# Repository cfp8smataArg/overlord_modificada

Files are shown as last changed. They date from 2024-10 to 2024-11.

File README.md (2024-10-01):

# Adaptación de impresora 3D Overlord Pro+
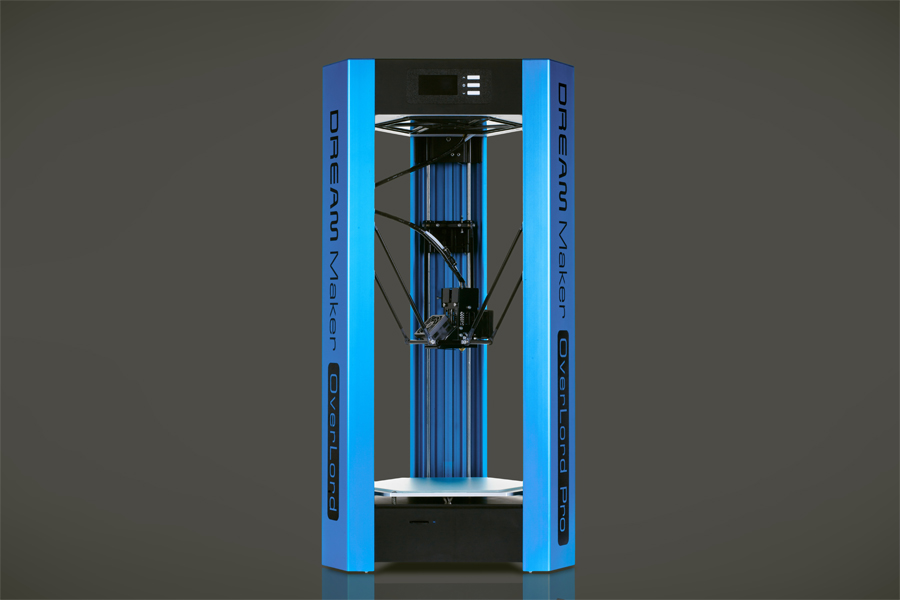
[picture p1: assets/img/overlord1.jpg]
overlord


El proyecto consiste en convertir la impresora 3D Overlord Pro+, de la empresa china Dream Maker, en una versión adaptable, de bajo costo, realizada con insumos mundialmente ultilizados por la comunidad maker y de facil acceso a nivel nacional.

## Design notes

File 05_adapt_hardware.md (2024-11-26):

---
title: Adaptación del hardware
layout: default
filename: 05_adapt_hardware.md
--- 
# Adaptación del hardware

En la sección [Planificación](./03_planificacion.html), se retiraron las partes de la estructura que cubren y protegen el cableado y la electrónica de la impresora 3D. Esto se hizo con el objetivo de despejar las zonas por las que se modificará el cableado original, se cambiarán los sensores y la electrónica de control.

Si la etapa de _Planificación_ fue realizada, la adaptación del hardware debe hacerse de forma ordenada, buscando que no exista ninguna confusión en el conexionado.
Antes de empezar con la adaptación del hardware, es importante saber que, debido a la [geometría delta](https://reprap.org/wiki/Delta_geometry) de la impresora 3D, el equipo tiene una gran extensión de partes cableadas. Para entender la estructura general de este cableado es importante tener los siguientes puntos bien presentes:

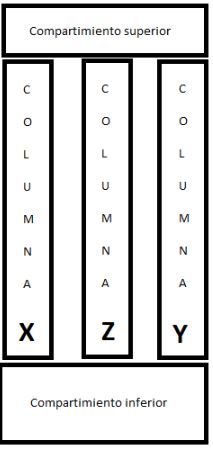
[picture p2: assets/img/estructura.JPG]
estructura


* La alimentación eléctrica que proviene de la fuente de alimentación de 24v ingresa desde un lateral del compartimiento inferior de la impresora 3D, de la misma manera que en el esquema original.
* Los motores de los tres ejes se encuentran en el compartimiento inferior.
* El final de carrera asociado a cada eje se ubica debajo de cada motor, sobre cada columna.

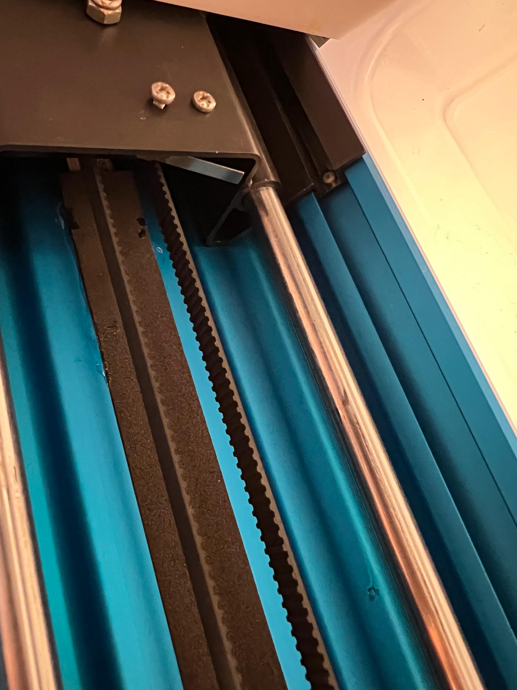
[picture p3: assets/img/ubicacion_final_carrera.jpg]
final_carrera
    

* El motor del extrusor se ubica dentro del compartimiento superior.

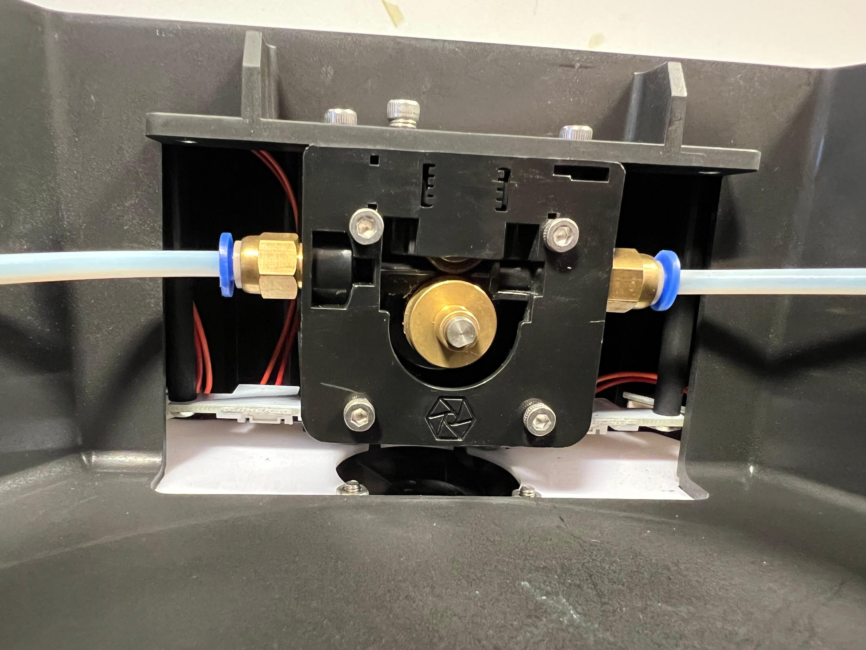
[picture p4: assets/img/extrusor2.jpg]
extrusor2
    

* En un costado de la parte interna del compartimiento superior, se ubica una placa pequeña, la cual interconecta todo el cableado eléctrico de algunos de los elementos que trabajan en bloque extrusor

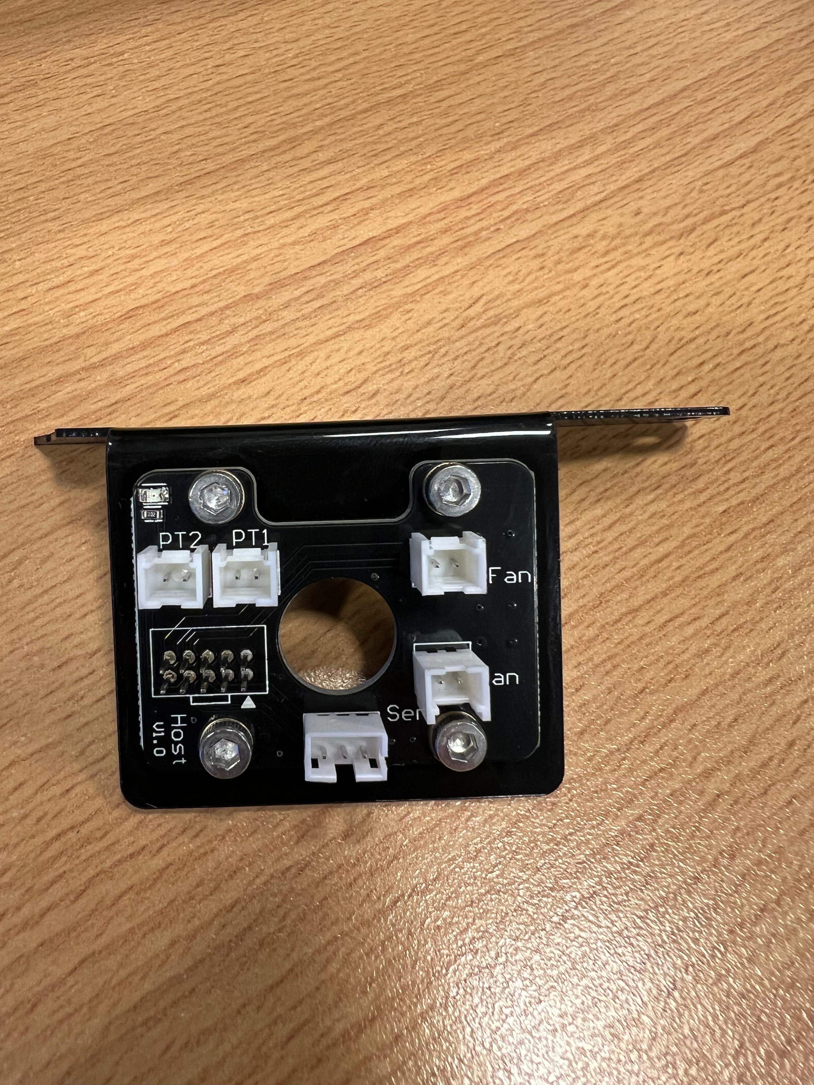
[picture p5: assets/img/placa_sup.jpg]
placa_sup
    

    Mediante un multímetro, es muy importante poder revisar el conexionado de todos los elementos que pasan por esta placa. Esto último ayudará a realizar el conexionado de los periféricos a la placa MKS.

* En el compartimiento inferior se ubica la placa de control MKS que controla la impresora 3D. Por las columnas desciende el cableado de todos los elementos que trabajan en el extrusor (coolers, calefactor 24v, termistor 100k).

## ¿Qué cables y elementos llegan al bloque extrusor?

Todos los elementos que llegan al extrusor lo hacen agrupados mediante un _spaghetti_. Estos elementos son los siguientes:

* Tubo de nylon por donde llega el filamento
* Cable del calefactor de 24V
* Cable del termistor NTC del bloque calentador
* Cable de 24v para los dos ventiladores de capa
* Cable de 24v para el ventilador del disipador

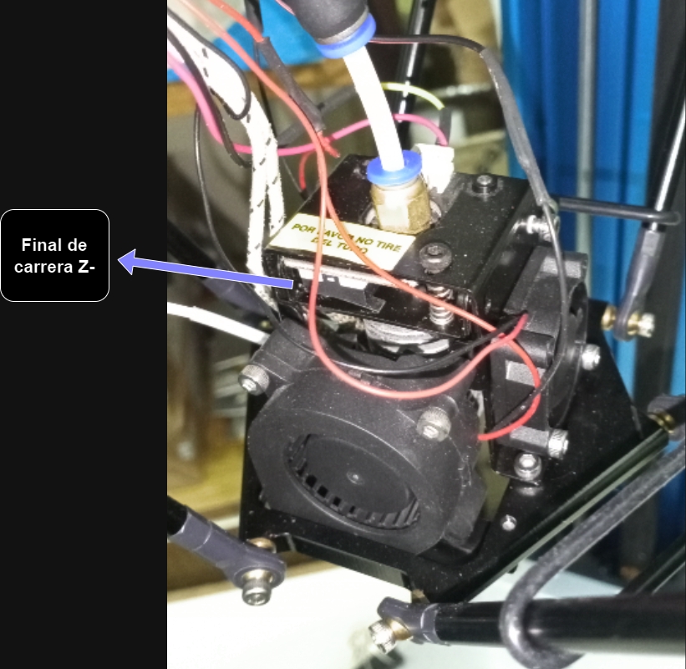
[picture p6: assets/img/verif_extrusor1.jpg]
verif_extrusor1

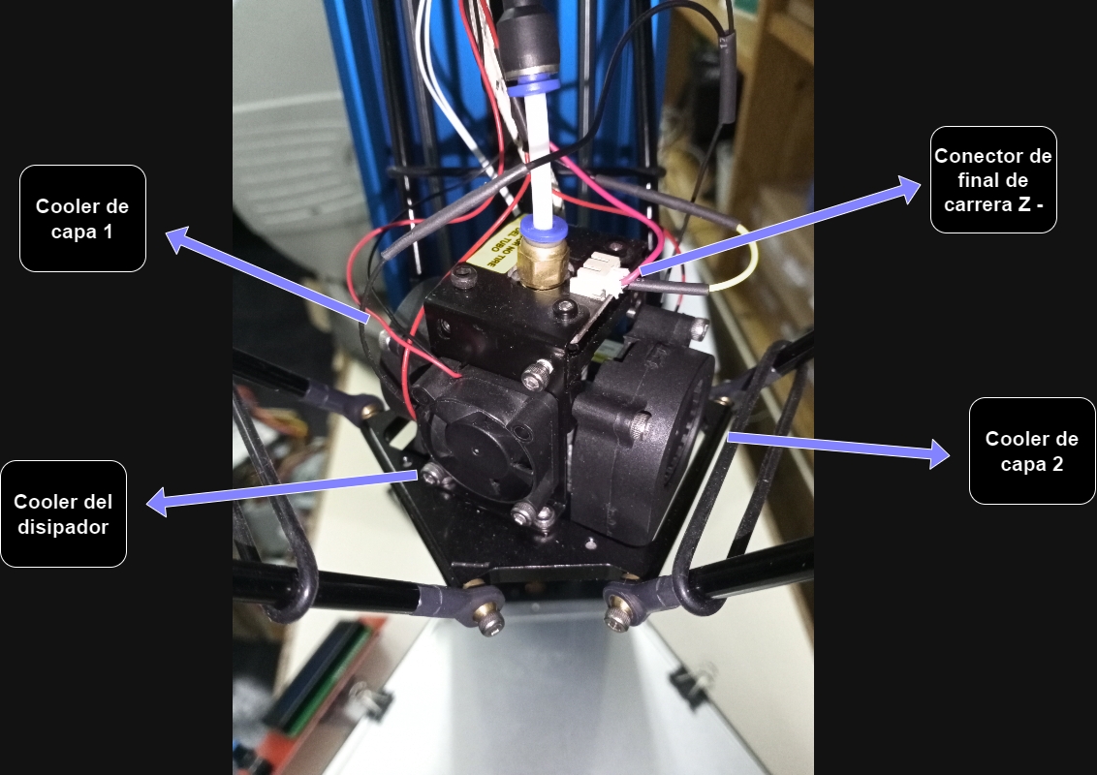
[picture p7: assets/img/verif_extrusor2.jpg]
verif_extrusor2

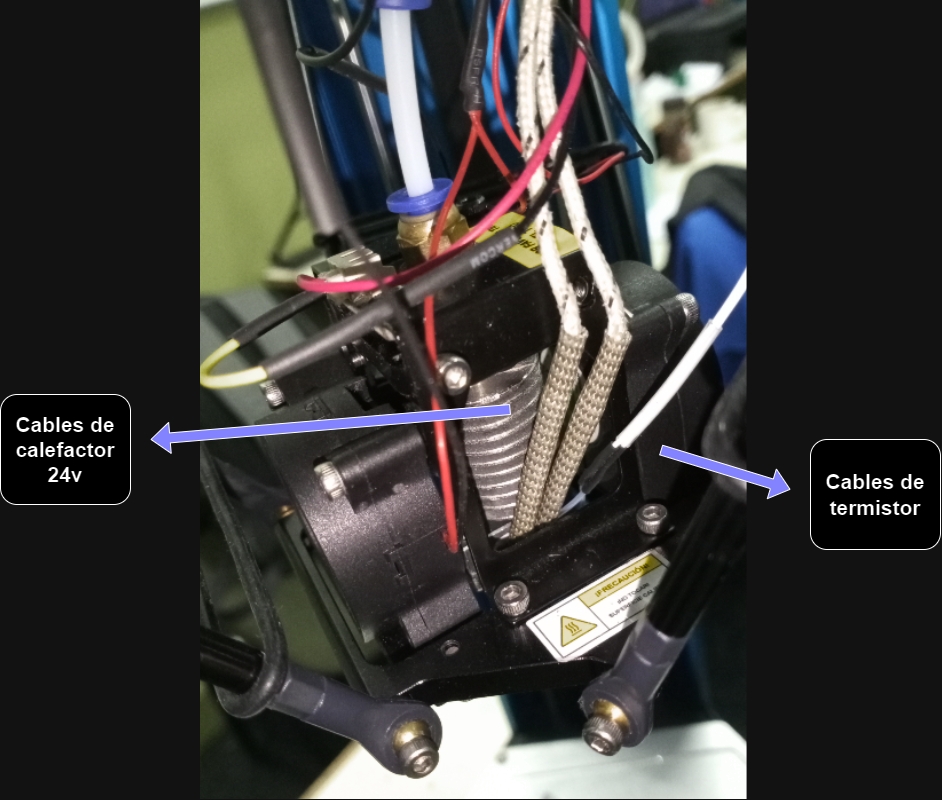
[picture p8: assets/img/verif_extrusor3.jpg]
verif_extrusor3

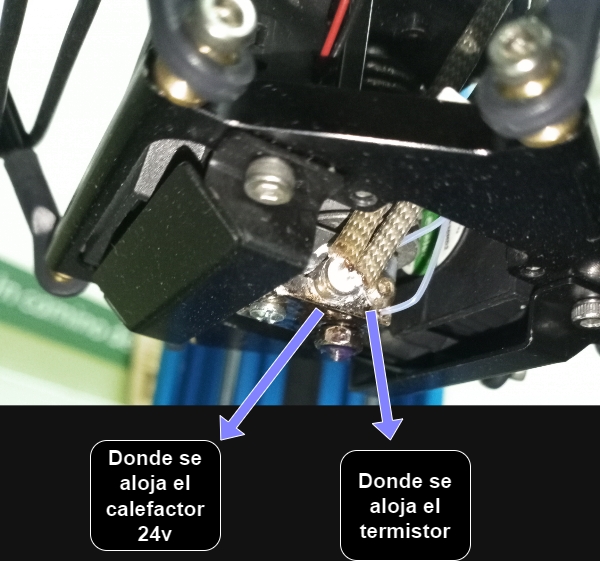
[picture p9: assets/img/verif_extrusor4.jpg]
verif_extrusor4


## Calibración de los drivers

El proceso de calibración de los drivers utilizados por los motores NEMA se muestra detalladamente en este [video](https://www.youtube.com/watch?v=GzAly4MJ4PU) para el driver **A4988** y este [video](https://www.youtube.com/watch?v=m1fOqq5GYDA) para el driver **DRV8825** _(Audio en inglés, pero tiene subtitulos en español)_.

## Adaptación de la fuente de alimentación

La fuente de alimentación original presenta en su cable un conector hembra de cuatro pines (dos para +24v y dos para GND). El conector macho es propio de la placa de control original del equipo. Dado que no es un conector fácil de encontrar en el mercado local, en este caso se reemplazó por una simple bornera de dos pines. Esto puede reemplazarse por otro conector que sea del gusto del usuario.

A continuación, están las imágenes del conector original del cargador y el conector original en el chasis de la impresora.

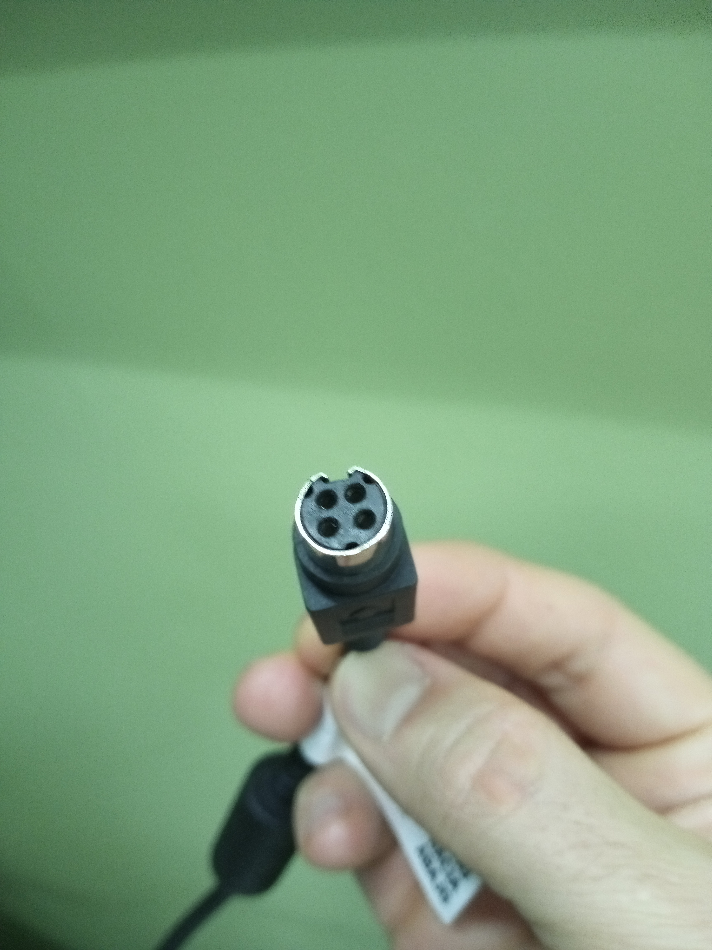
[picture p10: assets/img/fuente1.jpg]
fuente1

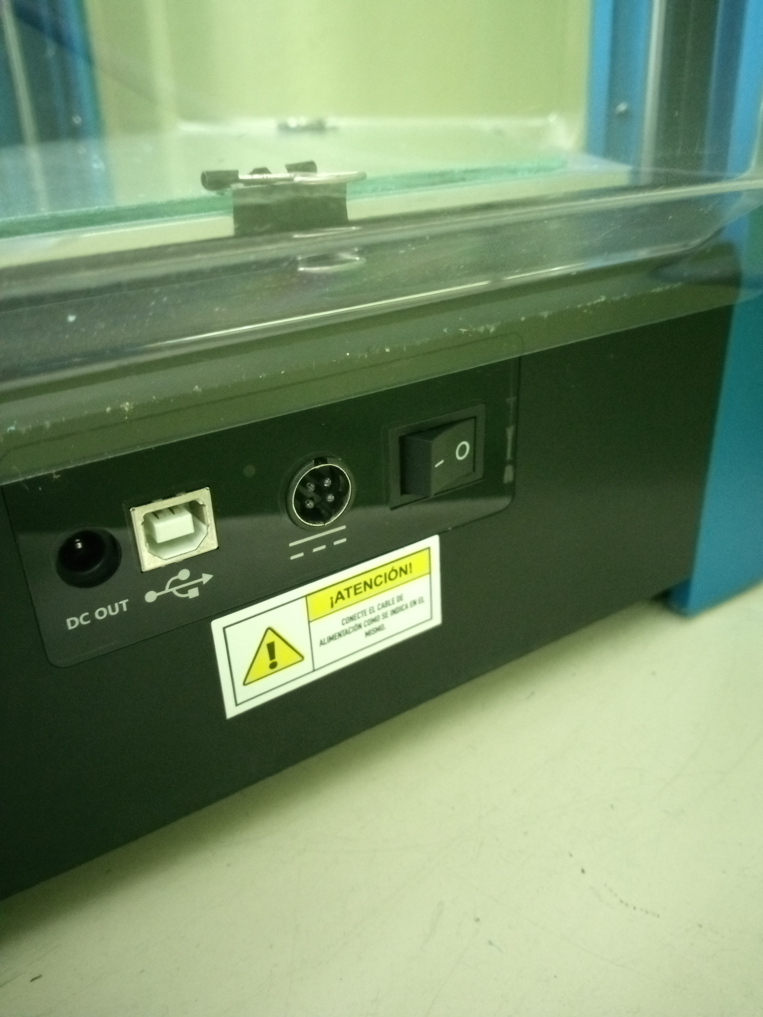
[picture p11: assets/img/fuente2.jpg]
fuente2


A continuación, están las imágenes donde se retira el conector y se dejan los dos cables libres y la bornera de dos pines para atornillar. El cable celeste y marrón son los de +24v y GND que ingresan a la impresora y alimentan todos los circuitos.

fuente3
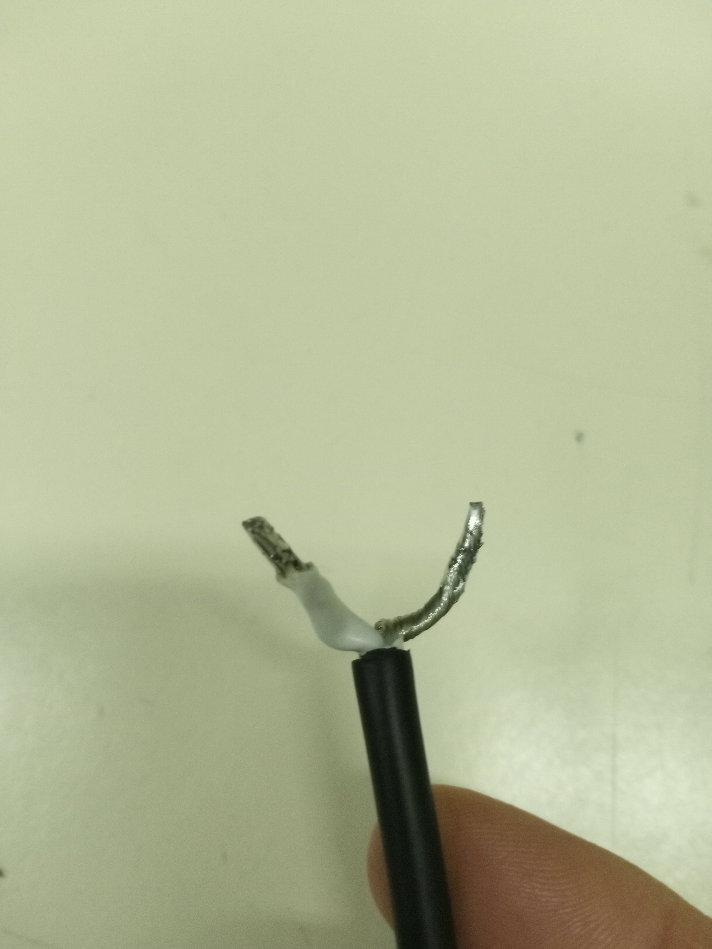
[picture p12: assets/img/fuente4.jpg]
fuente4


Firmware Puesta en marcha

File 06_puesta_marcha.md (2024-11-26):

---
title: Puesta en marcha
layout: default
filename: 06_puesta_marcha.md
--- 
# Puesta en marcha

Antes de comenzar a usar la impresora 3D por primera vez, es importante realizar una verificación de distintos módulos con el objetivo de prevenir algún posible accidente. Dado esto, es importante:

* Con un multímetro, verificar que la fuente de alimentación entrega el voltaje correcto.
* Verificar el cableado interno del equipo, asegurando que los cables no se enreden en el área de movimiento de los motores.
* Verificar la integridad de las correas en los tres ejes.
* Inspeccionar el extrusor y controlar todas las conexiones eléctricas que existen en él.
* Verificar las conexiones de todos los elementos en las placa de control.

Si los chequeos anteriores fueron realizados, avanzar con el encendido del equipo. El display se encenderá y aparecerá un menú como el de las siguientes imágenes.

marlin1
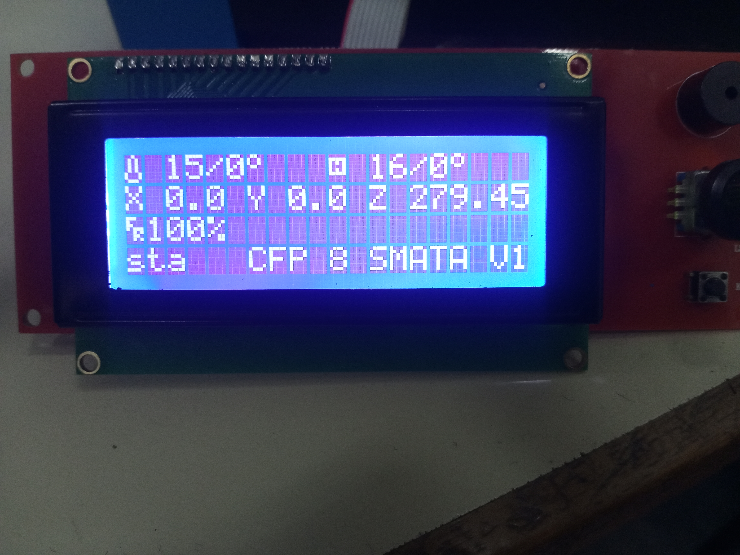
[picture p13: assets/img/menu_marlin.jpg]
marlin2


Hardware calibracion

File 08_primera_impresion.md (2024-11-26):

---
title: Mi primera impresión
layout: default
filename: 08_primera_impresion.md
--- 
# Mi primera impresión

La impresora 3D se opera de la misma manera que cualquier impresora 3D comercial.

1. Verificar que la cama caliente no presente suciedad. En caso de que sí exista, limpiarla con alcohol y un paño. 
2. Verificar que haya filamento cargado en la impresora 3D.
3. Cargar el archivo _.gcode_ a imprimir dentro de una memoria SD.
4. La memoria SD se inserta en el slot ubicado en el lateral del display LCD.
5. Al insertar la memoria SD, aparecerá la leyenda _SD/FD insertado_
6. Para lanzar la impresión, presionar el encoder, ir a la opción _Imprimir desde SD/FD_ y seleccionar el archivo a imprimir.

ATENCIÓN: En caso de atasco, nunca remover el tramo inferior del tubo de teflón (se muestra en la siguiente imagen) ya que una mala posición puede generar un desborde del filamento fundido y un posterior tapón y atasco de plástico.

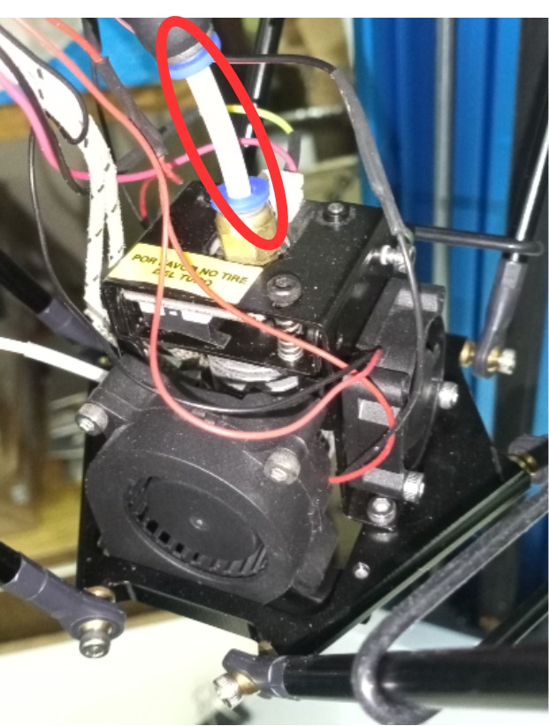
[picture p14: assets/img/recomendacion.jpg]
atención


# Demo

En el siguiente [link](https://drive.google.com/file/d/11Ifzz-wFGjBvnHKF1wgRUvqJJxLNcwyR/view?usp=sharing) se accede a un video demostración de la impresora 3D en funcionamiento. La impresión que se muestra en el video se realiza a 90 mm/s. A continuación, se muestra algunas imágenes de la impresión terminada.
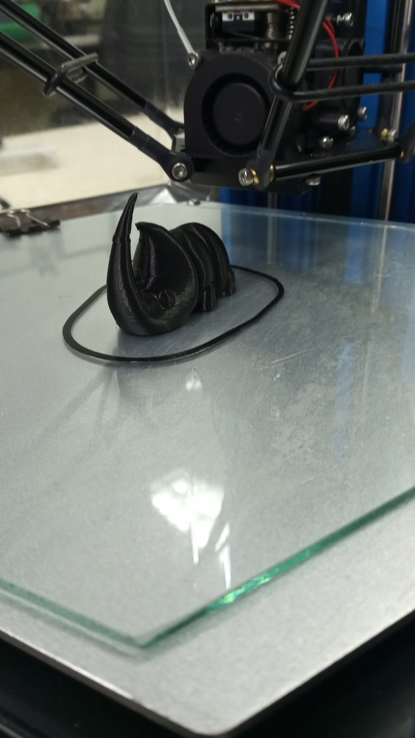
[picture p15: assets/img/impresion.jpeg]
impresion

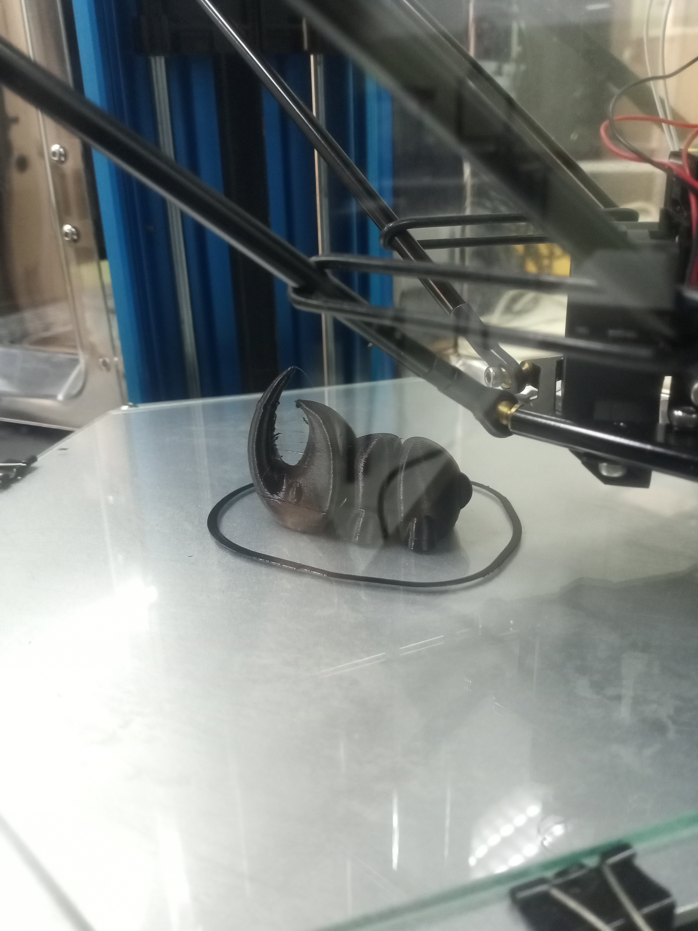
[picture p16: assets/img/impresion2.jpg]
impresion2


calibracion Agradecimientos

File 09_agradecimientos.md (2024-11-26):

---
title: Agradecimientos
layout: default
filename: 09_agradecimientos.md
--- 
# Agradecimientos
Este proyecto fue logrado gracias al apoyo y al trabajo del Centro de Formación Profesional Nº8 - SMATA y del INET. Este tipo de proyectos busca poner en valor recursos de las instituciones educativas de una forma simple y accesible, para que estudiantes y docentes de distintas puntos del país puedan poner en práctica los conocimientos vinculados a distintas áreas que son parte de la educación técnica como la robótica, el diseño y la impresión 3D, la electrónica, la programación y demás.

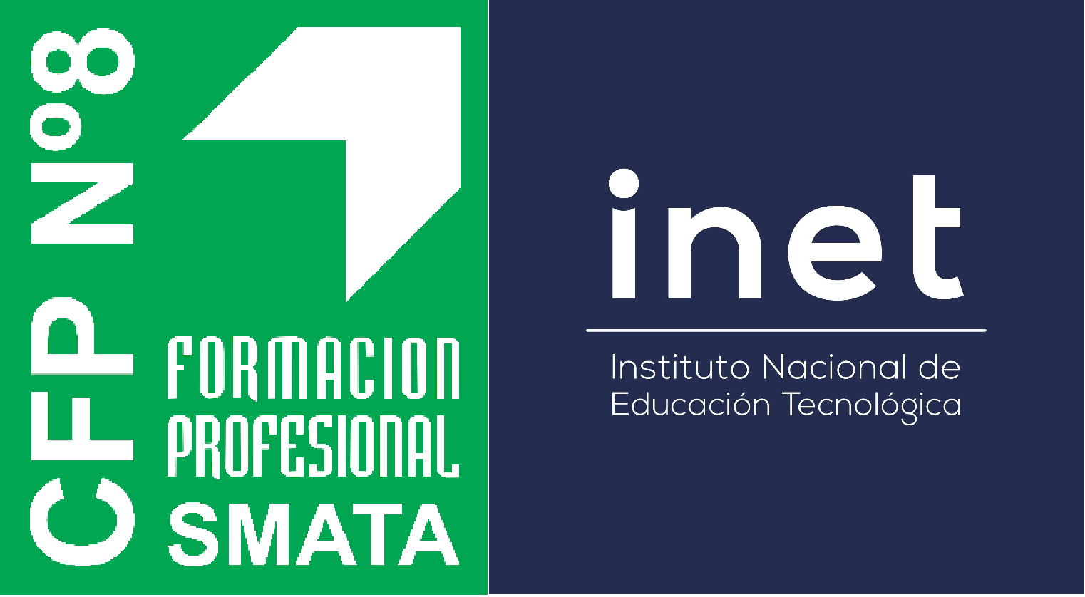
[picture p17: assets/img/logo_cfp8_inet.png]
logo_cfp8


Invitamos a todos los interesados a que puedan llevar adelante este tipo de proyectos y que puedan fomentar su creatividad y trabajo en equipo con el objetivo de apoyar el desarrollo de recursos educativos. Que la tecnología sea un medio de intercambio de ideas y motivaciones para todos los estudiantes.

Primera impresión

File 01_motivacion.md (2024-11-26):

---
title: Motivaciones y objetivos
layout: default
filename: 01_motivacion.md
--- 
# Motivaciones y objetivos
Desde el año 2019, el [Instituto Nacional de Educación Tecnológica (INET)](https://www.inet.edu.ar/) entregó a distintas instituciones educativas técnicas de todo el país cerca de 6000 impresoras 3D [Overlord Pro+](https://www.dfrobot.com/product-1298.html) con la intención de fomentar el diseño y la impresión 3D.

En el año 2020, la llegada de la pandemia intensificó el uso de este tipo de equipos para la impresión de vinchas para máscaras de protección contra el virus del COVID-19. La presencia de las impresoras 3D Overlord Pro+ en las escuelas generó que muchos establecimientos fueran centros de producción de vinchas a lo largo y a lo ancho del país.

Como cualquier dispositivo de uso cotidiano, las impresoras 3D requieren un mantenimiento preventivo y correctivo al sumar horas de uso. Las impresoras 3D Overlord Pro+ tienen la ventaja de que pueden ser puestas en funcionamiento de forma rápida y en pocos pasos, pero sus desventajas llegan cuando aparecen desperfectos técnicos.

Al pasar el tiempo, muchas de las impresoras 3D Overlord Pro+ que estaban en funcionamiento comenzaron a presentar desperfectos técnicos y comenzaron a dejar de utilizarse.

Una de las principales desventajas de este modelo de impresora 3D es que presenta un diseño “propietario”. ¿Qué significa eso? todas sus partes (firmware, electrónica, etc) son únicos de este modelo y no utilizan opciones genéricas o repuestos alternativos, como si lo hacen otros modelos de impresoras 3D de otras marcas del mercado local e internacional. Esto genera una gran dificultad para encontrar los repuestos necesarios, los cuales generalmente se encuentran discontinuados o presentan costos muy elevados.

El proyecto [RepRap](https://reprap.org/wiki/RepRap) propone el desarrollo de impresoras 3D a partir de diseños _Open Source_, entonces nos interesaba utilizar todo el conocimiento volcado sobre este proyecto colaborativo de escala mundial a la masa de impresoras 3D que podrían estar en desuso en las escuelas de toda la República Argentina.

>Una impresora 3D es una herramienta de trabajo y estudio invaluable, la cual dentro de una institución educativa o laboratorio tecnológico, permite estimular creatividad de forma ilimitada.

_"¿Cómo podemos hacer para que la impresora 3D Overlord Pro+ pueda ser lo más “genérica” posible?"_ _¿Como podemos hacer para que estas impresoras 3D puedan funcionar con insumos que puedan adquirirse en el mercado local a un bajo costo?_ _¿Cómo podemos hacer para que estas impresoras 3D se manejen como la mayoría de las impresoras 3D de uso doméstico a nivel mundial?_ Esto se preguntaron el Esp. Ing. Nicolás Vargas Alice y Freddy Fores, especialistas en diseño e impresión 3D, robótica y electrónica, quienes ademas son docentes del [Centro de Formación Profesional Nº8 - SMATA](https://centro8smata.org.ar/) e INET.

|:-----------------------------------------:|:------------------------------------------:|
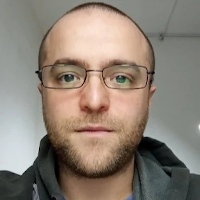
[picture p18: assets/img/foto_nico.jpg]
foto Nicolás
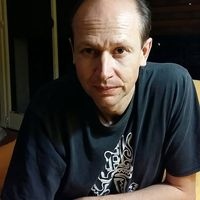
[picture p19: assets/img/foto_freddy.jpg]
foto Freddy
|||
|:-----------------------------------------:|:------------------------------------------:|
|      Esp. Ing. Nicolás Vargas Alice       |                     Freddy Forés           |

Desde inicios del año 2022 Nicolás y Freddy comenzaron a pensar las respuestas a todas estas preguntas. El equipo de trabajo comenzó a estudiar el funcionamiento de la impresora 3D, sus partes, la información disponible por parte del fabricante, etc. Luego de una etapa de estudio a investigación, se llegaron a las siguientes conclusiones:

* La impresora 3D presenta una excelente estructura mecánica.
* Las partes de la impresora 3D eran extremadamente costosas y muy complejas de conseguir en el mercado argentino.
* La documentación técnica existente era casi nula.
* El soporte técnico por parte del fabricante era inexistente.

A partir de estos cuatro puntos, se propuso desarrollar una adaptación de la impresora 3D que se base en: 
* Reutilizar partes originales de la impresora 3D
* Combinar las partes recicladas con insumos mas economicos y accesibles en el mercado local.
* Que el sistema de control de la impresora se base en un sistema fácil de configurar, simple de utilizar y con una amplia comunidad de usuarios a nivel mundial.
* Que el proceso completo de adaptación sea lo más accesible y claro para que estudiantes y docentes de las escuelas puedan ponerlo en práctica.

Inicio Materiales necesarios

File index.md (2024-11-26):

---
layout: default
---
# Bienvenidos al Proyecto!
En este sitio se encuentra el procedimiento detallado para realizar una posible adaptación de una impresora 3D modelo **Overlord Pro+** de la empresa **Dream Maker**. Esperamos que el trabajo relizado sea de utilidad y pueda ser puesto en práctica por parte de cualquier persona interesada.

El sitio está dividido en secciones que incluyen imágenes, enlaces de consulta e información complementaria que guían al usuario en la implementacion del proyecto.

# Antes de comenzar...
El proyecto fue desarrollado con la intención de que cualquier persona con mínimos conocimientos de electrónica y/o impresión 3D pueda implementarlo. Así todo, se recomienda leer detenidamente la información volcada en este sitio web y ante cualquier duda, comunicarse con los desarrolladores.

# Etapas del proyecto
Motivación  Materiales necesarios  Planificación

Firmware  Hardware  Puesta en marcha

calibracion  Primera impresión  Agradecimientos

# Contacto
Ante cualquier duda o consulta, comunicarse vía mail a: **inet.impresoras3d@gmail.com**

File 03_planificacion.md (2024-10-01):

---
title: Planificación
layout: default
filename: 03_planificacion.md
--- 
# Planificación

La etapa de planificación, como muchas de este proyecto, son modificables a gusto de las personas que lo estén llevando a cabo. El orden de estas tareas son únicamente una sugerencia propuesta. La idea de este paso es retirar partes del gabinete que protegen  parte del cableado y otros módulos para poder realizar cómodamente el retiro de las partes que no se utilizarán, las modificaciones en las partes a reutilizar e instalar las partes nuevas. 

Antes de comenzar, es bueno tener presente una vista integral de la impresora. La misma se puede observar en las siguientes imágenes, donde además se indican las partes principales de la misma.

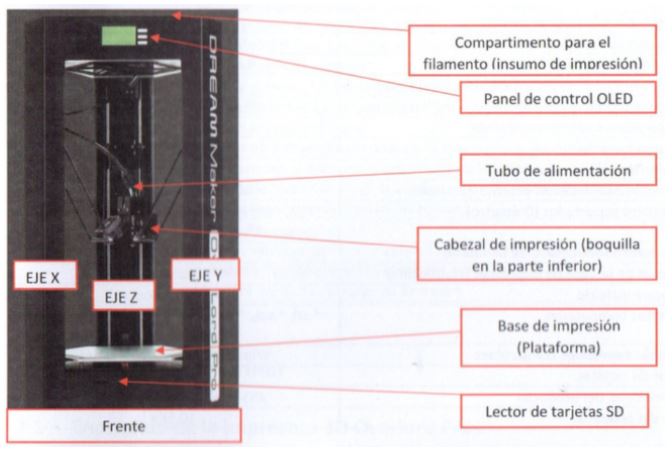
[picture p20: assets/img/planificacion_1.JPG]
planificacion_01

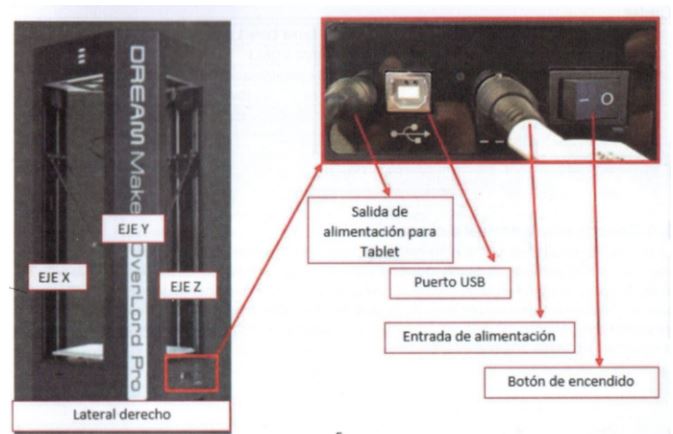
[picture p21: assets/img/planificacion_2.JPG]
planificacion_02


Teniendo presente esto, los pasos a seguir serían los siguientes:
* En el compartimiento superior, retirar la bobina de filamento que pueda estar utilizándose en la impresora 3D.
* Con un destornillador philips, retirar los paneles plásticos transparentes de los laterales y la tapa inferior que cubre la electrónica y parte del cableado de la impresora 3D.

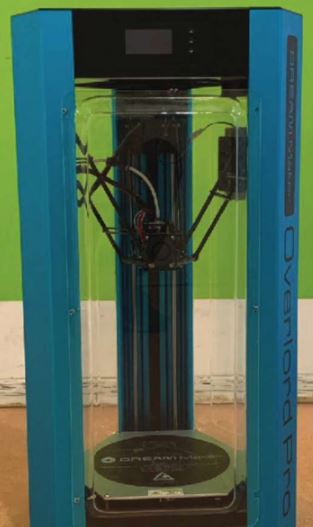
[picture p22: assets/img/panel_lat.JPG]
planificacion_03

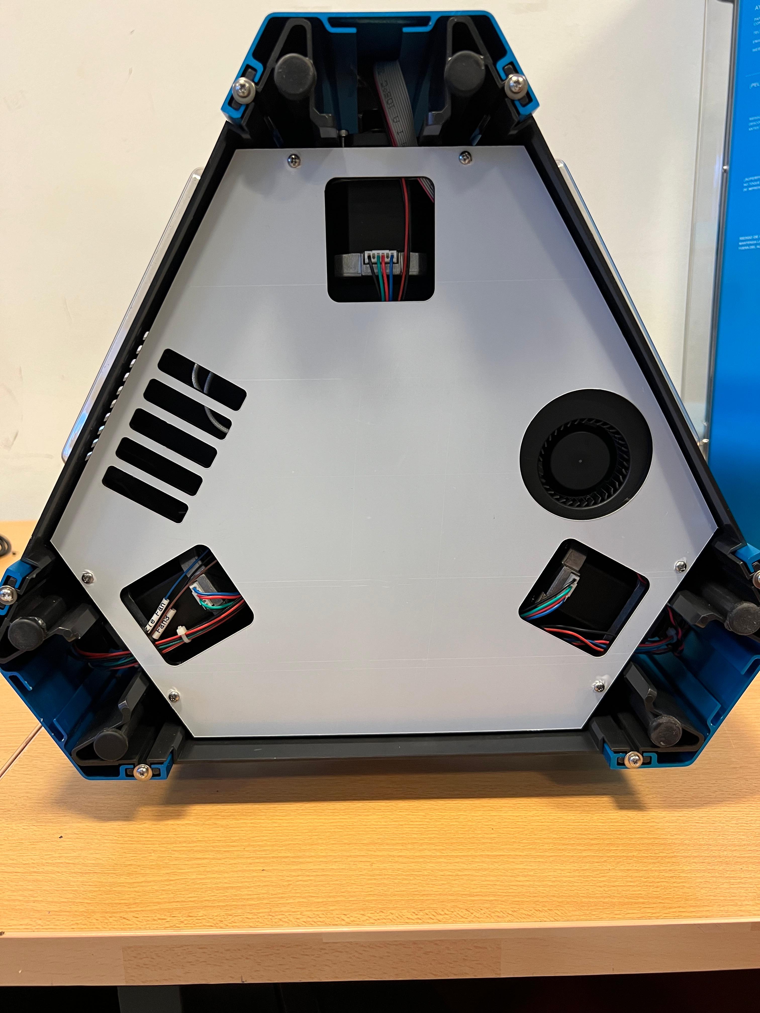
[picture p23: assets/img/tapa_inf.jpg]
planificacion_04


* El la parte inferior, debe observarse algo como lo de la siguiente imagen.

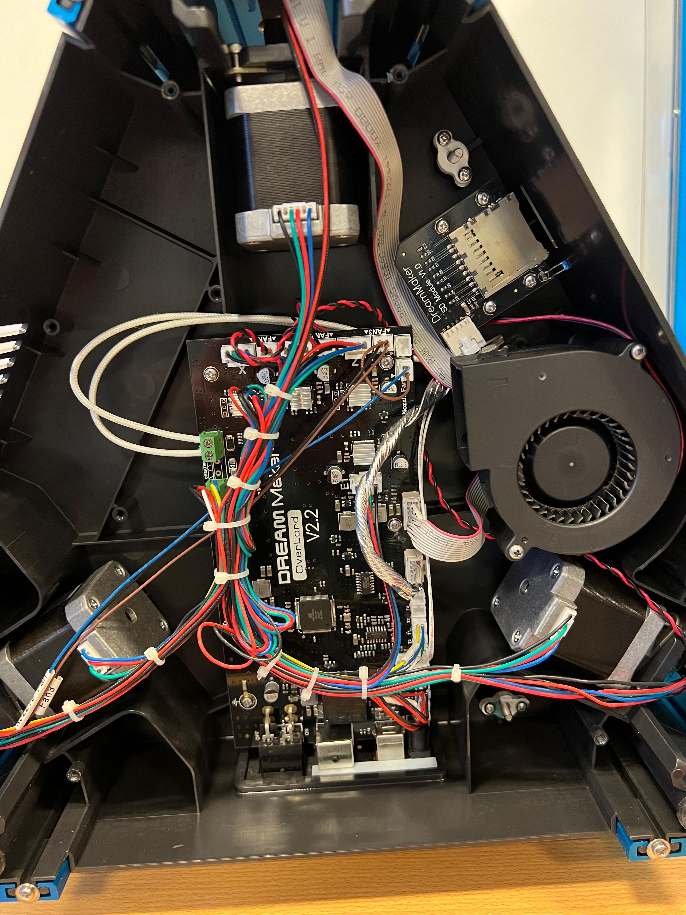
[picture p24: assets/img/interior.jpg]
planificacion_05


* Remover el covertor “__spaghetti__” que reúne el tubo de teflón blanco con cables que terminan en la zona del extrusor.
* Remover los perfiles celestes de las columnas. Para hacer esto, con un destornillador philips, remover los tornillos desde la parte inferior de la impresora 3D y deslizar los perfiles como muestran las siguientes imágenes.

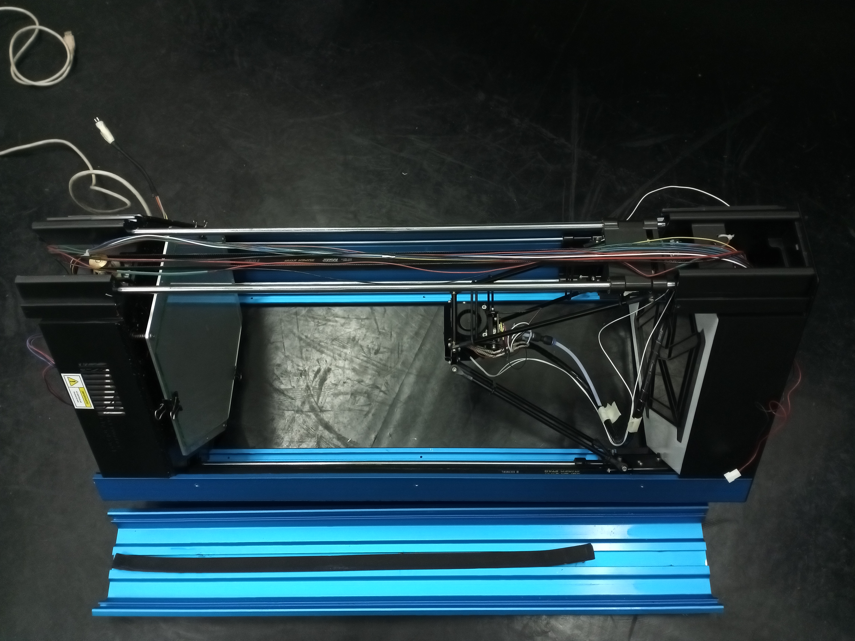
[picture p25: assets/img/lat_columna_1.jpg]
planificacion_06

planificacion_07

Materiales necesarios Firmware

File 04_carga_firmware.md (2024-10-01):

---
title: Instalación del firmware
layout: default
filename: 04_carga_firmware.md
--- 
# Antes de comenzar esta etapa

El firmware utilizado en este proyecto fue el Marlin 2.1.2. Se descargó el proyecto base desde la página oficial del __Proyecto Marlin__ y se modificó hasta lograr una versión funcional. La situación actual respecto al hardware (la placa MKS Gel-L v1.0 está discontinuada por el fabricante, pero aún se encuentran unidades a la venta. Se lanzó la placa [MKS TinyBee](https://github.com/makerbase-mks/MKS-TinyBee) como reemplazo) hace que **en este procedimiento mostremos la carga del firmware para ambas placas**.

Sin importar la placa con la que se trabaje, es importante tener una PC con los siguientes programas instalados:

* **Visual Studio Code**: IDE de programación mundialmente utilizado con el cual se puede modificar el código del firmware, compilarlo y cargarlo. De descarga desde este [link](https://drive.google.com/drive/folders/1mMvHacDkfZcnlTN5KPSEYk4WfQkbPL_f?usp=drive_link)
* **XLoader**: Programa para cargar archivos **.HEX** en la placa. Se descarga desde este [link](https://drive.google.com/drive/folders/1mMvHacDkfZcnlTN5KPSEYk4WfQkbPL_f?usp=drive_link).
* **Pronterface (Opcional)**: Programa para enviar comandos G a la impresora 3D y probar si la impresora interpreta bien los comandos. Se descarga desde este [link](https://www.pronterface.com/).

# Instalación del firmware en MKS Gen-L v1.0

Para instalar el firmware, proponemos dos opciones: 
* La primera opción es cargando el archivo **firmware.hex** mediante el programa **XLoader**, recomendada para usuarios que no tienen mucha experiencia en programación y prefieren hacerlo en pocos pasos. 
* La segunda opción es para usuarios que ya presentan alguna experiencia en programación, quieren explorar las opciones habilitadas dentro del código del Marlin o ya utilizaron los programas que se describieron más arriba. 

### Mediante programa XLoader

xloader

1. Conectar la placa a una PC mediante un cable USB Tipo B.
2. Con la placa conectada a la PC, abro el programa **XLoader**.
3. En _Device_, selecciono **Mega (ATMEGA2560)**.
4. En _COM port_, selecciono el puerto COM a donde tengo conectada la placa.
5. En _Hex File_, selecciono el archivo **.hex** (se descarga desde este [link](https://drive.google.com/drive/folders/1mMvHacDkfZcnlTN5KPSEYk4WfQkbPL_f?usp=drive_link))
6. Configurado todo, presiono el botón _Upload_.
7. Luego de unos segundos, en la parte inferior debe aparecer una leyenda como _“xxxxx bytes uploaded”_.
8. Listo, la placa ya tiene el firmware instalado.

>¿Qué es un archivo ```.hex```?
>
>Es un archivo con la información completa que queremos cargar en la placa, pero escrito en el _lenguaje_ que entiende la placa. Para explicarlo de una manera simple y sin demasiados detalles técnicos, cuando en programación hablamos de _“compilar código”_ el programa que ejecuta el proceso de compilación toma el archivo escrito en el lenguaje que hayamos trabajado nosotros (Por ejemplo, _lenguaje C_ o _C++_), verifica que no existan errores y finalmente genera el archivo resultado con extensión _.hex_.

>¿Qué es _código G_ O _G-Code_?
>
>El **G-Code** consta de comandos **G** y **M**, cada uno de ellos con un movimiento o acción asignado. La combinación de estos comandos permitirá a la impresora 3D entender qué patrón seguir con el fin de crear la pieza final. Entre los diferentes tipos de órdenes que interpreta la impresora 3D, encontramos comandos de movimiento, extrusión, calentamiento y detección en una secuencia.

### Mediante el programa Visual Studio Code

1. Con la placa conectada a la PC, abro el programa _Visual Studio Code_.
2. Instalar la extensión **Platformio** en el Visual Studio Code.
3. Abro el proyecto Marlin descargado desde este [link](https://drive.google.com/drive/folders/1mMvHacDkfZcnlTN5KPSEYk4WfQkbPL_f?usp=drive_link).
4. Una vez abierto el proyecto, me ubico en la barra inferior del programa y presiono la opción de **Upload** (tiene un icono de una flecha hacia la derecha).

    vsc1

5. Si no existió ningún problema, en la ventana **Console** debería aparecer un mensaje como el que muestra la siguiente imagen.

    vsc2

6. En caso de querer mas detalles del procedimiento, el el siguiente [link](https://marlinfw.org/docs/basics/install_platformio_vscode.html) se encuentra el procedimiento de carga explicado en el sitio del proyecto [Marlin](https://marlinfw.org/).

# Instalación del firmware en MKS TinyBee

Para cargar el firmware, también hay dos opciones: 
* Al igual que en el caso de la MKS Gen-L, la primera opción es cargando el archivo **firmware.bin** en una tarjeta microSD y energizar la placa mediante un cable USB C o la fuente de alimentación, opción recomendada para usuarios que no tienen mucha experiencia en programación y prefieren hacerlo en pocos pasos.
* La segunda opción es para usuarios que ya presentan alguna experiencia en programación, quieren explorar las opciones habilitadas dentro del código del Marlin o ya utilizaron los programas que se describieron más arriba.

### Mediante la carga del archivo **firmware.bin** en microSD

1. Descargar el archivo firmware.bin desde este [link](https://drive.google.com/drive/folders/1E1NkSHg_1MNqnraAo90TGFX9QdSg1mOr?usp=drive_link).
2. Cargar el archivo en una memoria micro SD manualmente.
3. Energizar la placa mediante un cable USB C a una PC o mediante la fuente de alimentación. Comenzará la instalación automáticamente.
4. Luego de que el firmware se haya instalado, extraer la memoria microSD. 
5. Para verificar que la instalación se hizo correctamente, abrir la memoria microSD en una PC. Si dentro de ella, hay un archivo **firmware.CUR**, esto indica que el firmware se instaló correctamente en la placa. Dicho archivo con extensión **.CUR** puede borrarse sin inconvenientes.

### Mediante el programa Visual Studio Code

1. Con la placa conectada a la PC, abro el programa _Visual Studio Code_.
2. Instalar la extensión **Platformio** en el Visual Studio Code.
3. Abro el proyecto Marlin descargado desde este [link](https://drive.google.com/drive/folders/1E1NkSHg_1MNqnraAo90TGFX9QdSg1mOr?usp=drive_link).
4. Una vez abierto el proyecto, me ubico en la barra inferior del programa y presiono la opción de **Upload** (tiene un icono de una flecha hacia la derecha).

    vsc1

5. Si no existió ningún problema, en la ventana **Console** debería aparecer un mensaje como el que muestra la siguiente imagen.

    vsc2

6. En caso de querer mas detalles del procedimiento, el el siguiente [link](https://marlinfw.org/docs/basics/install_platformio_vscode.html) se encuentra el procedimiento de carga explicado en el sitio del proyecto [Marlin](https://marlinfw.org/).

Planificación Hardware

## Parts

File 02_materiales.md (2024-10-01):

---
title: Materiales necesarios
layout: default
filename: 02_materiales.md
--- 
# Materiales necesarios

La lista de materiales se creó con el fin de optimizar y reutilizar la mayor cantidad de partes originales de la impresora 3D Overlord Pro+. En la siguiente lista se incorporan todos los elementos nuevos a adquirir, contemplando que los elementos originales existen y funcionan.

| **MKS GenL v1 (1 unidad)** |
|:---:|:---|
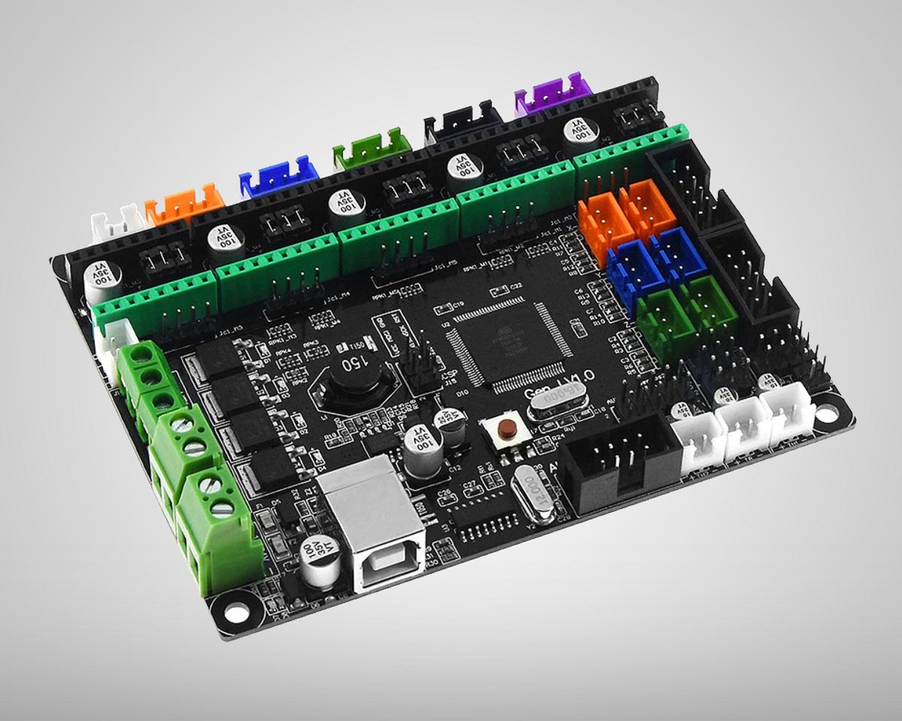
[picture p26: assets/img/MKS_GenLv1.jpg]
||Esta placa será la nueva placa de control de la impresora 3D. Será reemplazo de la placa original.|
| **Placa MKS Tiny Bee OPCIONAL** |
|:-----------------------------------------:|:-------------------------------------------|
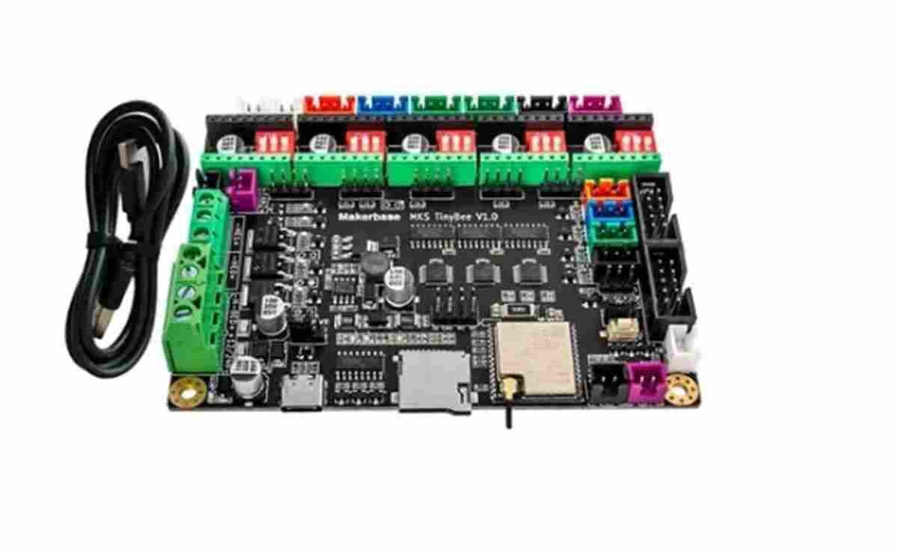
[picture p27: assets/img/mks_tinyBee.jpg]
foto MKS TinyBee
|Si la placa MKS Gen-L v1.0 no se encuentra en el mercado (actualmente discontinuada), la placa [MKS TinyBee](https://github.com/makerbase-mks/MKS-TinyBee) es el reemplazo directo por el fabricante.||
| **Display RepRap (1 unidad)** |
|:-----------------------------------------:|:-------------------------------------------|
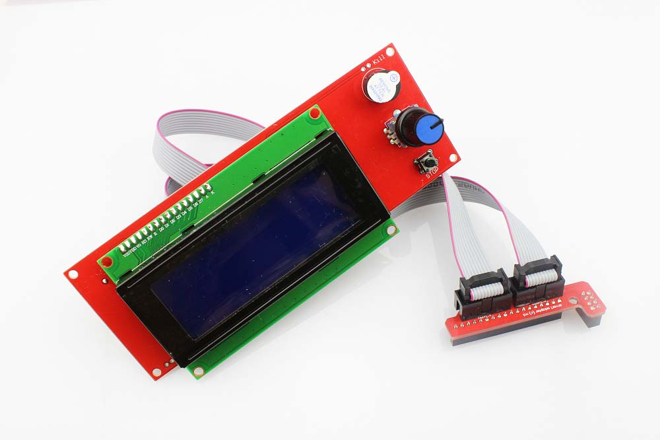
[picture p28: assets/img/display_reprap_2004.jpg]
display lcd 2004
||Este panel reemplazará el panel original. ¿Por qué no puede utilizarse el original? La programación y funcionamiento del panel original solo es compatible con la placa original de la impresora. Este panel es un modelo genérico compatible tanto con la placa MKS Gen L v1.0 como también con muchísimas placas existentes en el mercado. Al adquirir el panel de usuario, vendrá un paquete con todos los elementos que hay en la imagen. En esta adaptación no usaremos la pequeña placa roja con conectores negros, solo se utilizará el panel y los dos cables grises.|
| **Driver A4988 o DRV8825 (4 unidades)** |
|:-----------------------------------------:|:-------------------------------------------|
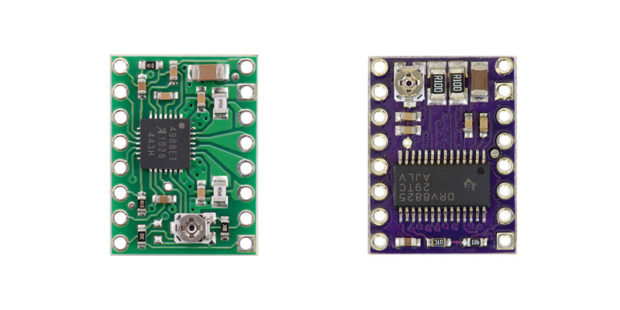
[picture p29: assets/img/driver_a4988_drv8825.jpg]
drivers
|Se pueden utilizar cualquiera de los dos drivers: el A4988 (color rojo o verde comúnmente) o el DRV8825 (color violeta). La principal diferencia entre ambos drivers es que el DRV8825 soporta una corriente máxima de 2.5A, mientras que el A4988 soporta 2A.||
| **Multímetro** |
|:-----------------------------------------:|:-------------------------------------------|
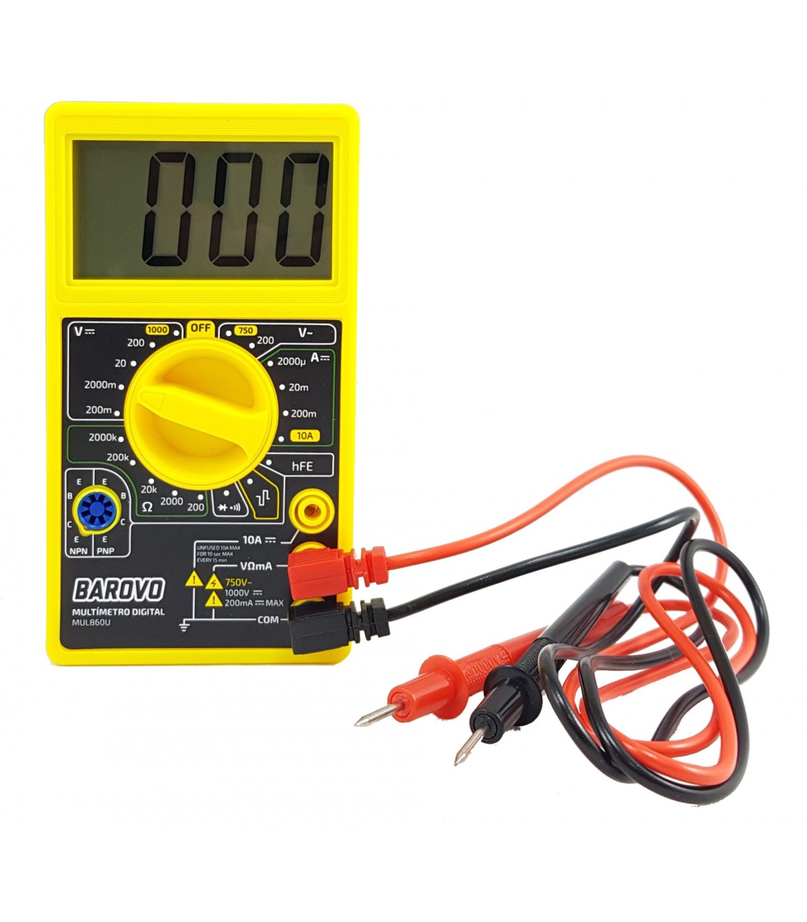
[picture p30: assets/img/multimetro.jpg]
multimetro
||Este instrumento nos ayudará a realizar mediciones a lo largo de todo el proyecto.|
| **Soldador tipo lápiz y estaño** |
|:-----------------------------------------:|:-------------------------------------------|
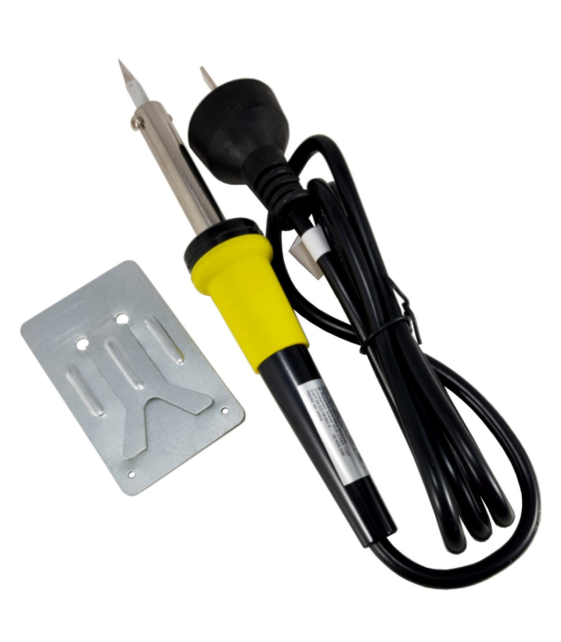
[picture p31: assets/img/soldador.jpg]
soldador
|El soldador y el estaño nos ayudarán a hacer las uniones del cableado, principalmente en el caso de los ventiladores.||
| **Pinza y alicate** |
|:-----------------------------------------:|:-------------------------------------------|
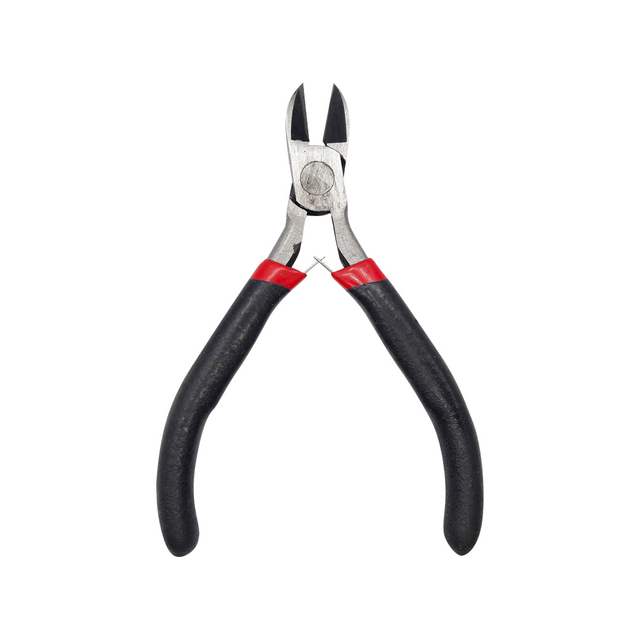
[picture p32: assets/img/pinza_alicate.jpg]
pinza_alicate
||La pinza y el alicate son herramientas que pueden utilizarse durante el proceso.|
| **Perilleros** |
|:-----------------------------------------:|:-------------------------------------------|
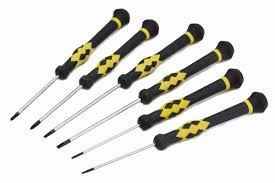
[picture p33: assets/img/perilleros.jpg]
perilleros
|Los perilleros son otros elementos muy utilizados durante la implementación del proyecto.||
| **Destornilladores** |
|:-----------------------------------------:|:-------------------------------------------|
|destornilladores|Al igual que los perilleros, los destornilladores son otros elementos muy utilizados durante la implementación del proyecto.|
| **Termistor 100k b3950 (2 unidades)** |
|:-----------------------------------------:|:-------------------------------------------|
|El extrusor y la cama caliente llevan un termistor NTC 100K b3950 cada uno. Estos se encargan de sensar la temperatura de trabajo de la impresora 3D.|termistor|
| **Termocontraible (medidas: 1 y 2 mm)** |
|:-----------------------------------------:|:-------------------------------------------|
|termocontraible|El termocontraible se utilizará para cubrir empalmes que se deban hacer durante el procedimeinto.|
| **Tecla 24v** |
|:-----------------------------------------:|:-------------------------------------------|
|La tecla se encargará de encender o apagar el equipo desde el panel lateral.|tecla_24|
| **Bornera** |
|:-----------------------------------------:|:-------------------------------------------|
|bornera|La bornera conectará los hilos que provienen desde la fuente de alimentación.|
| **PC** |
|:-----------------------------------------:|:-------------------------------------------|
|La pc es necesaria para cargar el firmware de control en la placa principal de la impresora 3D.|PC|
| **Cable USB Tipo B** |
|:-----------------------------------------:|:-------------------------------------------|
|usb_b|Si trabajaremos con la placa MKS Gen-L, vamos a necesitar este cable para conectar la placa a la PC.|
| **Cable USB Tipo C** |
|:-----------------------------------------:|:-------------------------------------------|
|Si trabajaremos con la placa MKS TinyBee, vamos a necesitar este cable para conectar la placa a la PC.|usb_c|

## A continuación se detallan las piezas originales que se reutilizan en este proyecto.

| **Motores NEMA** |
|:---:|:---|
|foto MKS Gen L|Se reutilizaron los cuatro motores originales de la impresora 3D. Tres para las columnas y uno para el sistema de extrusión del filamento.|

| **Cama caliente** |
|:---:|:---|
|Debido al material y a la dimensión, se utilizó la cama caliente original de la impresora 3D.|cama|

| **Bloque Extrusor** |
|:---:|:---|
|extrusor|El bloque extrusor original se utilizó de forma intacta, preservando el pico caliente, el bloque calentador, el disipador, el ventilador del disipador y el ventilador de capa.|

| **Coolers** |
|:---:|:---|
|Originalmente, el equipo tiene seis coolers. 3 en el extrusor: 1 para el disipador y 2 de capa. Coolers en el espacio de trabajo: 1 pequeño sobre el techo del área de trabajo y otro sobre el lateral, en una de las paredes de plástico transparente. Uno ubicado en la parte inferior interna de la impresora, lugar donde se ubican los motores y la electrónica del equipo.Únicamente se mantuvo el funcionamiento de los tres ventiladores del extrusor y el ventilador interno que refrigera la electrónica del equipo.|coolers|

| **Estructura** |
|:---:|:---|
|extrusor|La estructura general del equipo se mantuvo intacta.|

| **Fuente de alimentación** |
|:---:|:---|
|Se reutiliza la fuente original de la impresora 3D, únicamente modificando su terminal de conexión.||

| **Finales de carrera** |
|:---:|:---|
|Se reutilizan los cuatros finales de carrera que presenta la impresora 3D: uno en la parte superior de cada comuna y uno en el extrusor.|extrusor|

Motivación Planificación

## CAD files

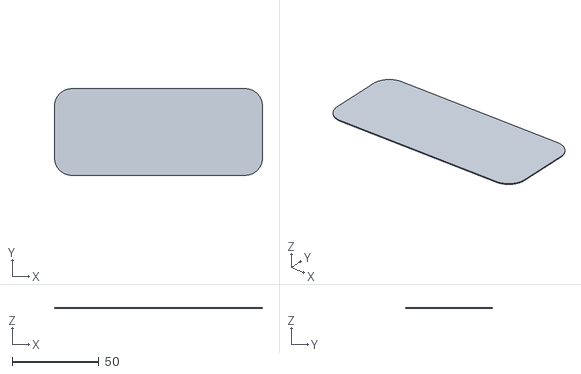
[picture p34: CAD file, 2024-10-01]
stl/tapa_display.stl
120.0 x 50.0 x 0.5

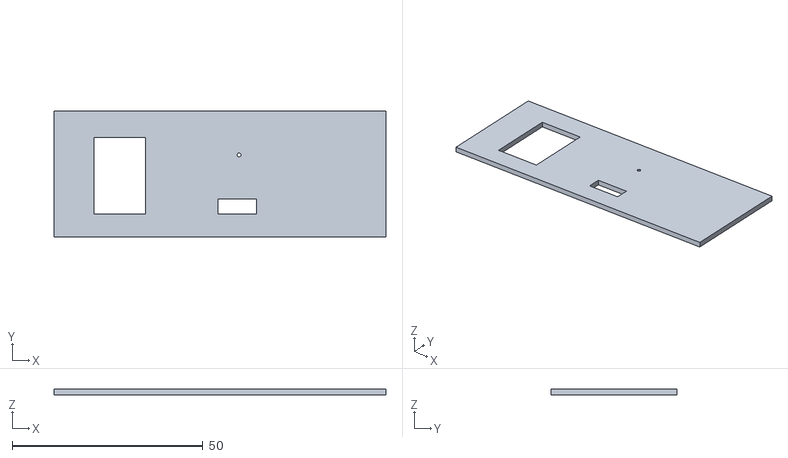
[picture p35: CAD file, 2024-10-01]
stl/frente_bornera_tecla.stl
87.0 x 33.0 x 1.50

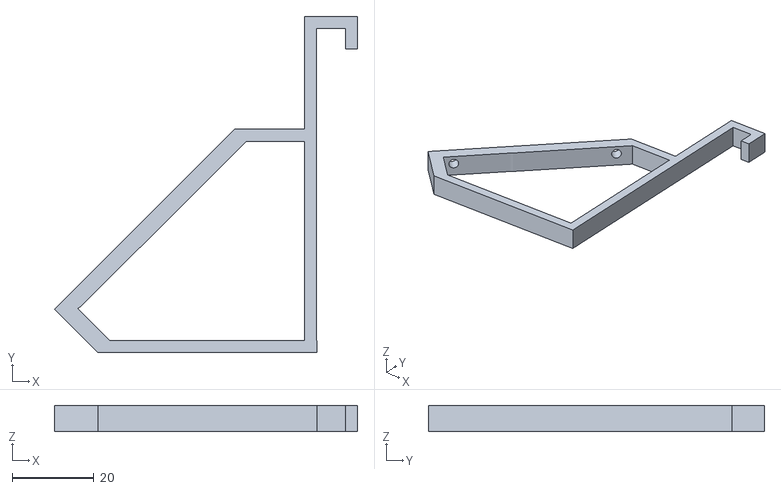
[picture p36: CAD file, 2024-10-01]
stl/soporte_lcd.stl
74.3 x 82.5 x 6.50

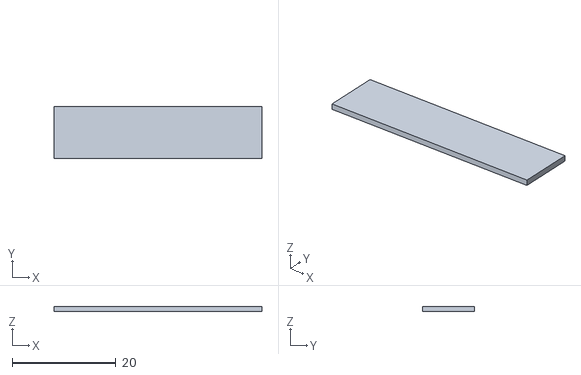
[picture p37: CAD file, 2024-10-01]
stl/tapa_slot_sd.stl
40.0 x 10.0 x 1.00

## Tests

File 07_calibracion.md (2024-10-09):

---
title: Calibración
layout: default
filename: 07_calibracion.md
--- 
# Calibración del equipo

La calibración general de la impresora 3D está dividida en dos partes: calibración de la cama y ajuste de altura Z.

Para hacer la calibración integral del equipo se entiende que las verificaciones explicadas en la [Puesta en marcha](./06_puesta_marcha.html) fueron realizadas con éxito.

## Calibración de la cama

1. Presionar el encoder. Ir a _Configuración -> Calibración Delta -> Auto Calibración_. Al elegir esta opción, cada brazo asociado a cada columna buscará su origen. Luego, descenderá hasta aproximadamente 4mm del centro de la cama caliente.

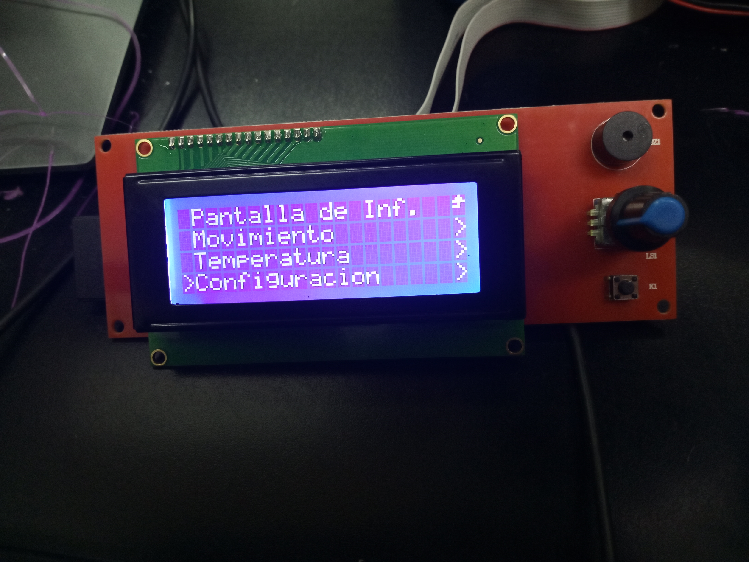
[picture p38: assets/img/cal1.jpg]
cal1
    
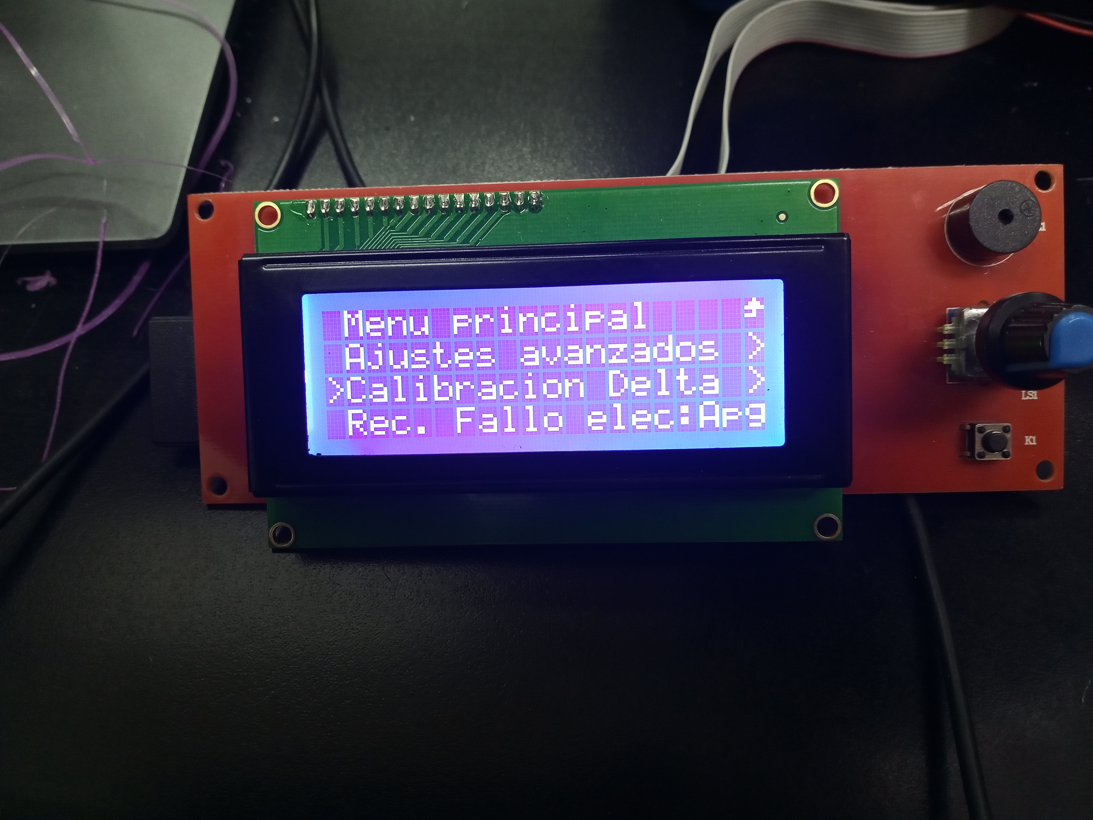
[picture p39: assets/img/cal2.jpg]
cal2
    
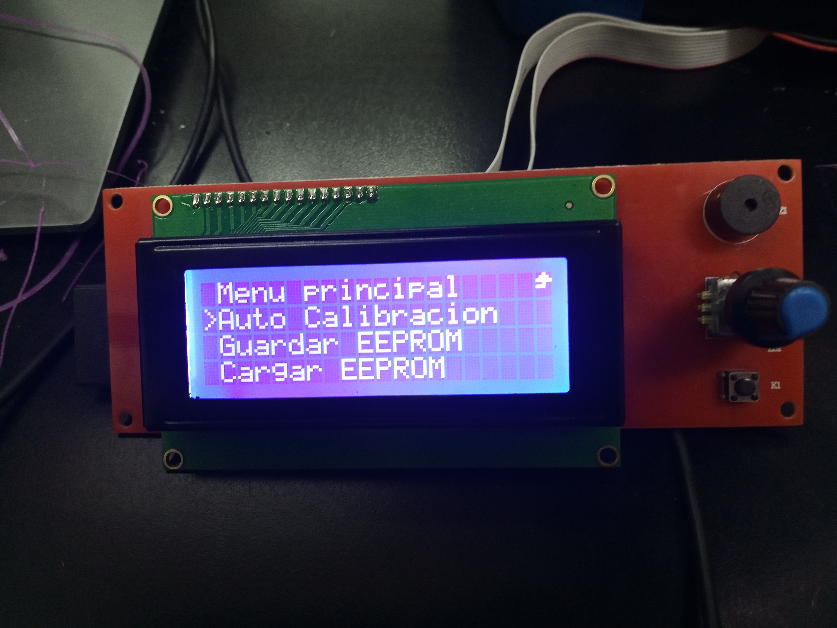
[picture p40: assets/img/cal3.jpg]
cal3
    

2. A partir de acá, el proceso de **Auto Calibración** consiste en generar un mapa de la cama caliente mediante la navegación de ```16pts``` por toda la superficie de la cama. A continuación, se detalla el mapa de los puntos, por que punto comienza el proceso y por cual termina.

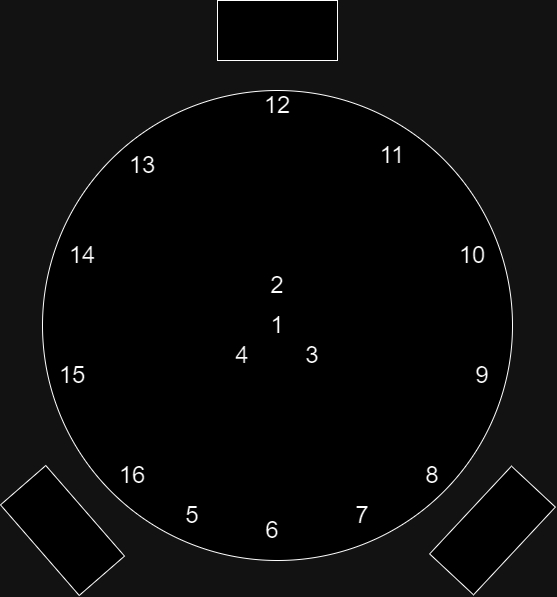
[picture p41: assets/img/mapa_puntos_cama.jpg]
mapa_puntos_cama
    

Cada punto recorrido se ubicará en ```Z = 004.000mm``` y requiere determinar la altura correcta entre la cama caliente y el pico. Para esto, con la ayuda de un papel, voy rotando el encoder hasta lograr que el papel se mueva debajo del pico con una leve resistencia. Los saltos en Z serán de ```0.25mm```.

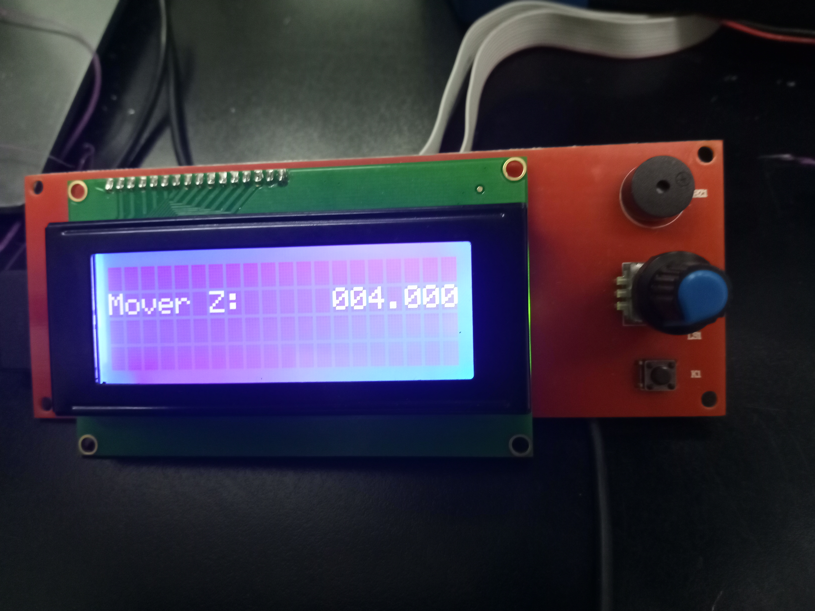
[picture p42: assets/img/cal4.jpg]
cal4
    
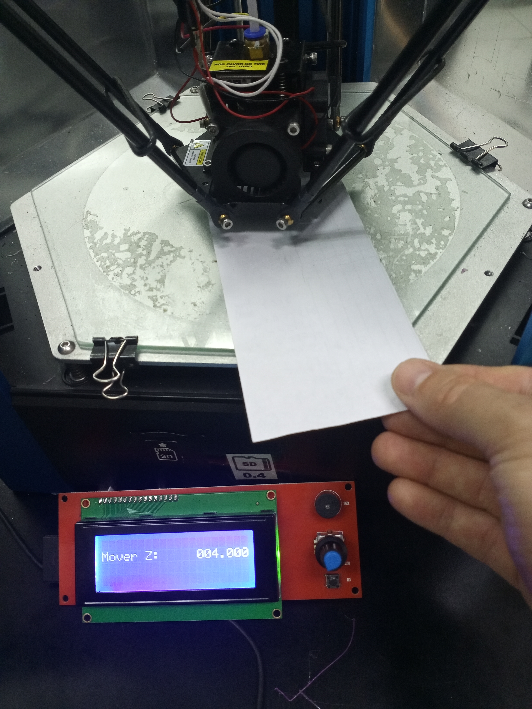
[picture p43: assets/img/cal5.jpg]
cal5
    

3. Al terminar la recorrida por los ```16pts```, en la pantalla aparecerá una leyenda que dice _Calibration sd: N_. **N** es el [desvío standard](https://es.wikipedia.org/wiki/Desviaci%C3%B3n_t%C3%ADpica), un valor que representa cuán dispares están los puntos de la cama caliente. Si el valor es mayor a ```0.5```, se recomienda repetir el proceso.

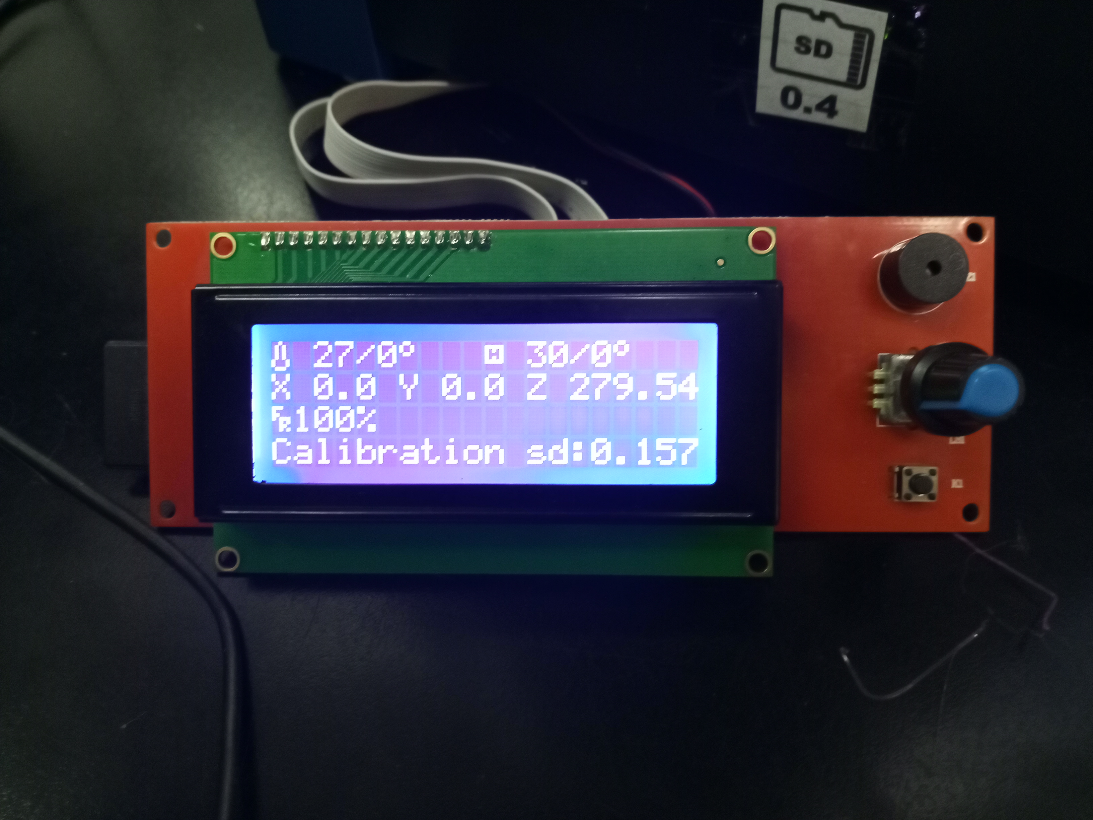
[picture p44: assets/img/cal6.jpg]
cal6
    

4. Como ultimo paso, ir a _Configuración -> Guardar EEPROM_

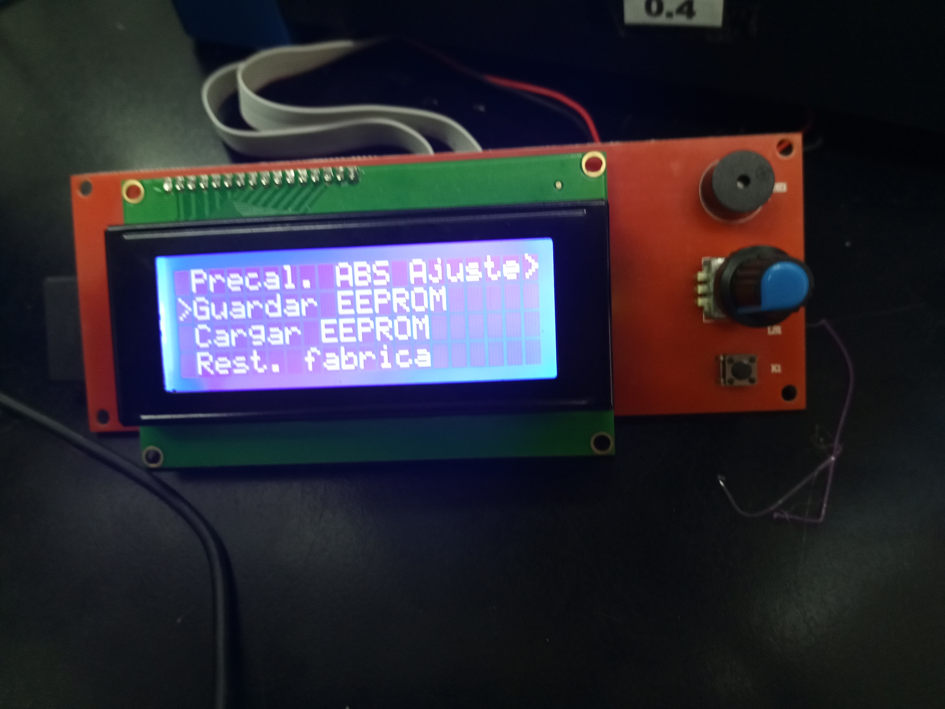
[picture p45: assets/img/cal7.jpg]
cal7
    
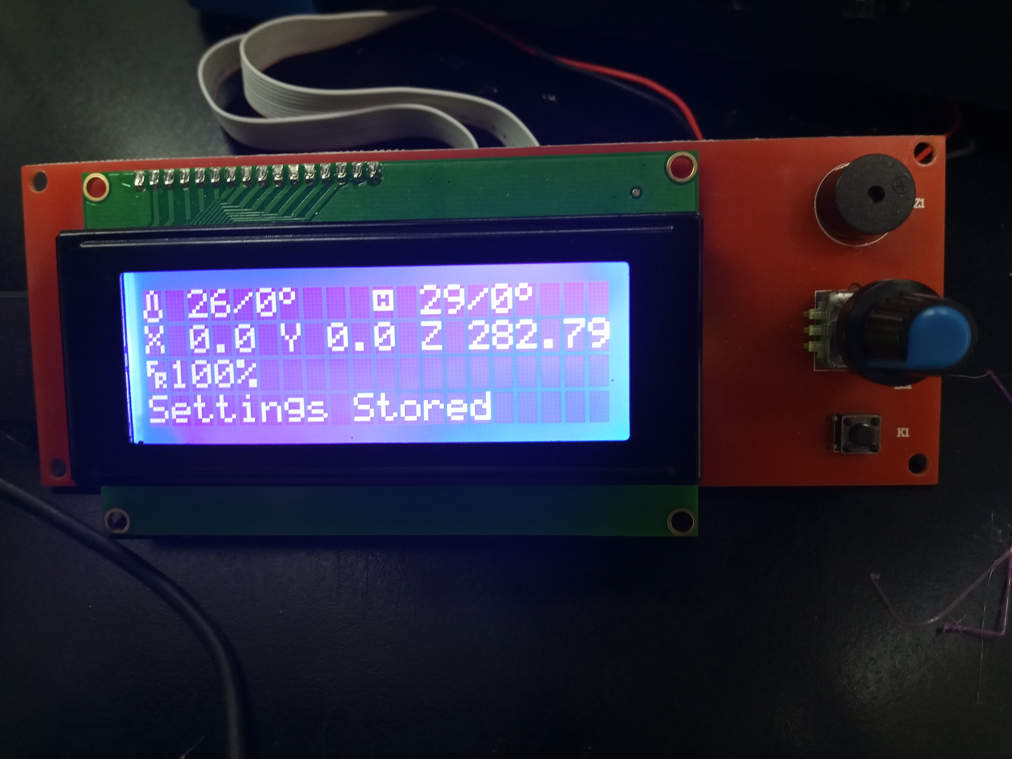
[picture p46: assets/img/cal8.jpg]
cal8
        

## Ajuste de altura en Z

1. Presionar el encoder. Ir a _Movimiento -> Llevar al origen_. Al elegir esta opción, cada brazo asociado a cada columna buscará su origen.

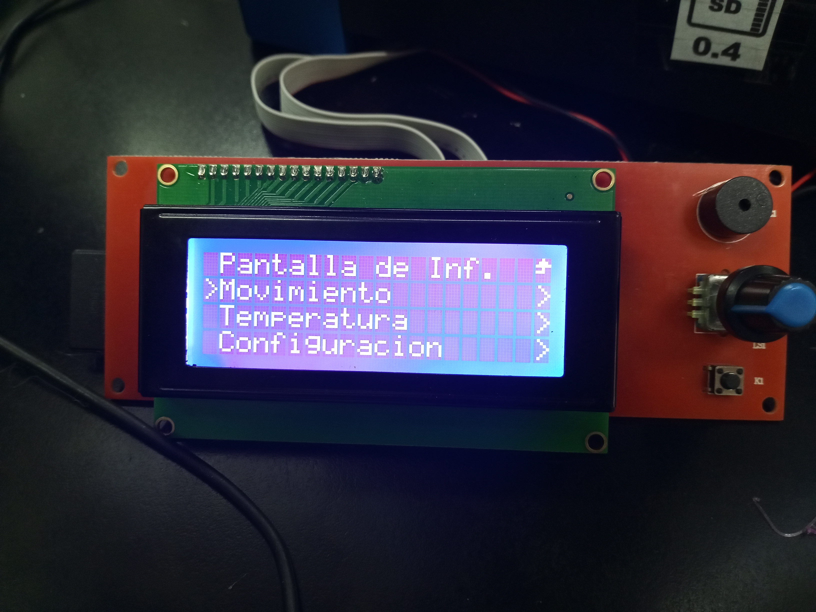
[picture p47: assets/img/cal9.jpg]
cal9
    
    cal10  

2. Ahora, se debe corregir la altura en Z. Para esto ir a _Movimiento -> Mover ejes -> Mover Z_. Con el encoder, bajar el pico hasta que se llegue a una distancia óptima entre el pico y la cama caliente.

    cal11
    cal12 
    cal13
    cal14

3. Cuando se logre una distancia óptima entre el pico y la cama caliente, la pantalla marcará _Mover Z:     VALOR_. **Anotar este valor!**

    cal15

4. Con el valor de Z anterior, debemos corregir la altura de Z que se encuentra guardada en el sistema. Para esto ir a _Configuración -> Calibración Delta -> Configuración Delta -> Altura_.
    + Si el **VALOR** registrado en el punto anterior es **positivo** se debe hacer este cálculo: **(Z actual - VALOR)** y guardar el resultado (ejemplo: si Z=279.45 y VALOR=0.05, entonces: Z corregido = 279.45 - 0.05 = 279.4).
    + Si el **VALOR** registrado en el punto anterior es **negativo** se debe hacer **(Z actual + VALOR)** y guardar el resultado (ejemplo: si Z=279.45 y VALOR=-0.05, entonces: Z corregido = 279.45 + (-0.05) = 279.45 - 0.05 = 279.4).

    cal15b

5. Como último paso, ir a  _Configuración -> Guardar EEPROM_

    cal16
    cal17

### _"¿Cuándo tengo que hacer estos procedimientos?"_

Se recomienda hacerlos luego de que se haya manipulado la impresora para cambiar alguna parte, luego de varias impresiones o si la impresora se movió de lugar.

Puesta en marcha Primera impresión

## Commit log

2024-10-09 agregado de imagenes
2024-11-26 agregado de logos
